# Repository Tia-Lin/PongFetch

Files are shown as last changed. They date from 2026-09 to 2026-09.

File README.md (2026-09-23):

# PongFetch · rev 3.0

**Pick.Play.** A 3D-printable table-tennis ball picker with a removable PVC handle.

Press the frame over 40 mm balls. Three flexible fins let the balls pass into a mesh net; eight folding latches secure the net. A six-finger collet and screw cap hold the handle without glue, so it can be reused.

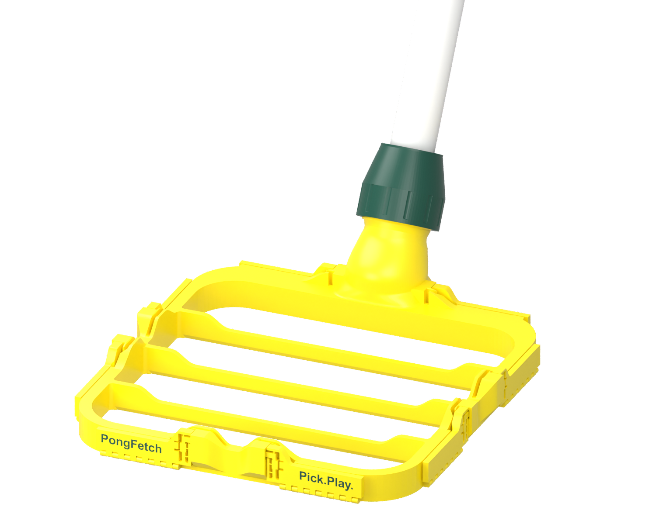
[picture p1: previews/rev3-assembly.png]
PongFetch assembled


**[Download rev 3.0](https://github.com/Tia-Lin/PongFetch/releases/tag/v3.0)** · [Printing](prints/PRINTING.md) · [Assembly](docs/ASSEMBLY.md) · [Accessories](Accessories/README.md) · [License](LICENSE.md)

## Make one

Print one frame, one collet and one cap. Add a fine mesh net and a PVC pipe matching the design's **21.34 mm outside diameter**. Measure the actual pipe before printing; the size printed on plumbing pipe is not its outside diameter. Net pins are 2.8 mm in diameter, so check that your mesh can pass over them.

| File | Use |
| --- | --- |
| [Frame 3MF](prints/PongFetch_Rev3_Frame.3mf) | Frame, eight folding latches, flush two-colour lettering and local bridge modifiers |
| [Handle parts 3MF](prints/PongFetch_Rev3_Handle_Parts.3mf) | One collet and one cap, in their saved print orientations |
| [Frame STL](SmallPicker.stl) | Single-colour frame; no visible flush lettering |
| [Collet STL](Collet.stl) · [Cap STL](ColletCap.stl) | Single-part meshes for your own slicer setup |

The release includes individual print files, an editable-design ZIP, a complete **Maker Bundle**, and SHA-256 checksums. GitHub's automatic source archive contains the repository; the Maker Bundle is the curated printing download.

The validated mechanical parts were printed in PETG. Review the saved **4 walls and 0.20 mm layers / first layer**. **Select your actual printer, plate and loaded materials, then re-slice both 3MF projects.** The files save different machine profiles; they are not ready-to-send G-code. See [the exact saved settings](prints/PRINTING.md).

After cooling, release the three thin first-layer ties at each latch. Place the net between the flap and frame, engage the pins through the mesh, and keep the net clear of the release spring. Seat the collet's locating skirt and hand-tighten the cap. No glue is needed.

## Accessories

Two optional attachments for the free end of the same PVC handle are now included in the Maker Bundle and in the separate [Accessories download](https://github.com/Tia-Lin/PongFetch/releases/download/v3.0/PongFetch_Accessories.zip).

| Accessory | Print project | Details |
| --- | --- | --- |
| Decorative end cap | [Two-colour end cap](Accessories/EndCap/PongFetch_EndCap_Logo_X2D_PETG_Basic.3mf) | User-selected ID 21.44 mm, OD 23.84 mm, 1.20 mm wall; flush paddle-and-ball logo |
| Removable hanger (D) | [Hanger and compression nut](Accessories/Hanger/PongFetch_Hanger_X2D_PETG_Basic.3mf) | Two printed parts; clamps to the pipe without glue or drilling |

Both accessory projects save X2D / 0.4 mm / PETG Basic / textured PEI / 0.20 mm layers / 4 walls, with supports disabled. Re-slice for the actual printer and loaded materials. The user has approved the end-cap fit and reported the hanger works well; long-term load capacity is not rated. See [Accessories](Accessories/README.md) for assembly and validation scope.

The 2026-09-22 accessory supplement leaves the core rev 3.0 geometry and published core print files unchanged. The `v3.0` tag still identifies the original core release; updated download bundles record their source commit in `PACKAGE_INFO.json`.

## What is validated?

The current frame, skirted collet and cap have been physically printed and reported stable and usable by the designer. Rev 3.0 adds four flush labels: `PongFetch`, `Pick.Play.`, `open source`, and `rev 3.0`. Their orientation is defined for the **closed, assembled flaps**.

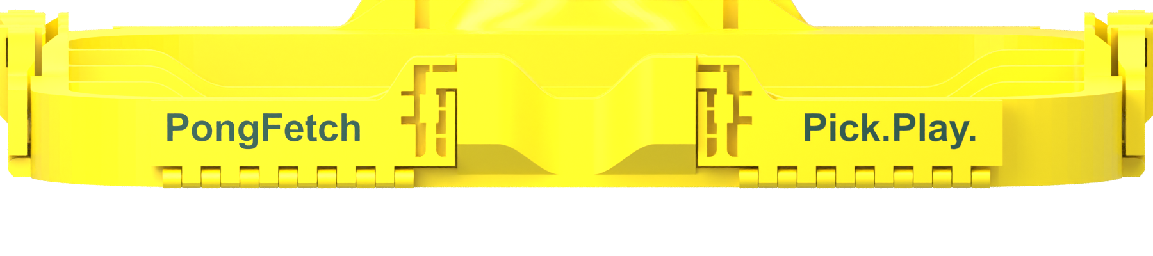
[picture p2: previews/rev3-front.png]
Front labels

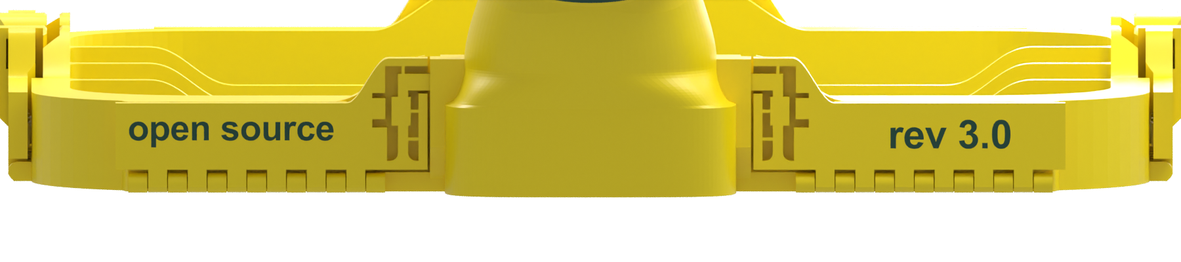
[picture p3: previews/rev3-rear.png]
Rear labels


The 0.60 mm text inlay and material partition were checked digitally. The coloured finish and long-term durability have not been established by those checks. This publication preserves the current CAD, STL and 3MF files; it adds no untested mechanical revisions. See [validation scope](docs/VALIDATION.md).

## Edit the design

Install [OpenSCAD](https://openscad.org/) and [BOSL2](https://github.com/BelfrySCAD/BOSL2) separately. Put BOSL2 in OpenSCAD's library search path. Open `SmallPicker.scad` with the other three SCAD files beside it.

| Source | Contents |
| --- | --- |
| `SmallPicker.scad` | Frame, flat-bottom fins, latch placement and part selection |
| `SideLatch.scad` | Side-release latches, net pins and first-layer ties |
| `ColletSocket.scad` | Socket, locating-skirt collet and screw cap |
| `Branding.scad` | Text, assembled orientation and inlay depth |

Choose `part` in the Customizer: `frame`, `cap`, `collet`, `assembly`, or `exploded`. For two colours, export `frame_base` and `frame_text`, then import them **as parts of one object at their shared coordinates**, without separately centering them. `Arial:style=Bold` is used for the text; use a licensed local font or change `brand_font` and recheck text fit. No font or BOSL2 files are bundled.

With Python 3 and OpenSCAD on your PATH:

```sh
python3 scripts/export_parts.py --parts cap collet
python3 scripts/verify_release.py
```

Omit `--parts` to also export the frame; that can take several minutes. Use `--openscad /path/to/openscad` if needed. The existing export baseline used OpenSCAD 2021.01; the exact installed BOSL2 revision was not recorded, so recheck exports after changing dependencies.

## Repository and contributions

This repository contains the product design, print files, documentation and compact verification reports. The product website is maintained separately; its application code is no longer part of this repository. Design downloads and releases remain available here. Slicer logs and old prototypes are excluded from the published tree.

For a bug report or improvement, [open an issue](https://github.com/Tia-Lin/PongFetch/issues) with the revision, printer, nozzle, material, layer height, wall count and a photo. For a design change, include editable source and describe what you tested. Keep print orientation, support-free printing and net routing in mind.

## License

The original design materials are **CC BY-NC-SA 4.0**: noncommercial copying, printing and adaptation are permitted under the license; shared work must retain attribution, identify changes and comply with ShareAlike. Commercial use requires separate permission where licensed rights are involved. Sharing editable source with a remix is encouraged, not an extra license requirement.

Read [LICENSE.md](LICENSE.md) for scope and attribution, the unmodified [official legal text](CC-BY-NC-SA-4.0.txt), and [third-party notices](THIRD_PARTY_NOTICES.md). Website application code and Python utilities remain outside the design-license grant.

Because commercial reuse is restricted, this is a **source-available design for noncommercial use**, not an OSI open-source project. The historical `open source` label on the model does not change the license.

## 中文快速说明

本套件为 rev 3.0：框身（含八只翻片）、压紧夹头、锁紧螺帽各一件。另需网袋和外径约 21.34 mm 的 PVC 管；先量实际管径。优先下载 Release 的 Maker Bundle，双色文字使用框身 3MF，单色 STL 不显示齐平嵌字。

保留已经验证的机械结构及最新打印项目。打开 3MF 后选择自己的打印机、材料和打印板并重新切片；两张打印盘保存的机器配置不同。释放每只翻片的三条首层细筋，再装网、安装可拆把手。详见[打印说明](prints/PRINTING.md)和[装配说明](docs/ASSEMBLY.md)。

可选 [Accessories 配件](Accessories/README.md) 已并入完整下载包：最终双色装饰帽，以及可拆卸 D 挂钩和旋紧环。已有主体可以单独下载 Accessories 包。

采用 **CC BY-NC-SA 4.0（署名—非商业性使用—相同方式共享）**，具体范围以 LICENSE.md 及官方许可原文为准。

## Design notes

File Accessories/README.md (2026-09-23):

# Accessories

Optional accessories for the **free end** of the PongFetch PVC handle. Choose the decorative cap or the removable hanger; both target a pipe with **21.34 mm actual outside diameter**.

| Accessory | Ready-to-slice project | Assembly and source |
| --- | --- | --- |
| End cap with flush paddle-and-ball logo | [End cap 3MF](EndCap/PongFetch_EndCap_Logo_X2D_PETG_Basic.3mf) | [EndCap](EndCap/README.md) |
| D removable hanger and compression nut | [Hanger 3MF](Hanger/PongFetch_Hanger_X2D_PETG_Basic.3mf) | [Hanger](Hanger/README.md) |

The end cap uses the user-selected **ID 21.44 mm / OD 23.84 mm / 1.20 mm wall** fit. It is decorative and is not a hanging attachment. The hanger clamps onto the tube without glue or drilling and releases by loosening its nut. The user has reported successful use of both designs; the hanger is not load-rated.

Both projects save **X2D, 0.4 mm nozzle, textured PEI, PETG Basic, 0.20 mm layers and four requested walls, supports disabled**. Open them in Bambu Studio, select the actual printer and spools, then re-slice. They contain no machine-ready G-code. The end cap is a single object with two colour parts; the hanger project contains its two separate printable pieces.

STLs, editable OpenSCAD source and compact verification records are included in each folder. EndCap source is standalone; Hanger source requires separately installed BOSL2. Trial directories and older fit variants have been removed from the active release.

Download the standalone **PongFetch_Accessories.zip** or the complete **PongFetch_Rev3_Maker_Bundle.zip** from the [rev 3.0 release](https://github.com/Tia-Lin/PongFetch/releases/tag/v3.0). The original core tag is unchanged; refreshed bundles identify their source commit in `PACKAGE_INFO.json`.

## 中文

Accessories 包含最终双色装饰帽，以及可拆 D 挂钩和旋紧环。两者用于 PVC 管的另一端，按需要二选一。帽子采用已试好的最紧尺寸，挂钩保留已验证结构；主体 rev 3.0 不变。

原型目录已清理。可以单独下载配件包，也可以下载已经包含配件的 Maker Bundle。打开 3MF 后按实际打印机和 PETG 料卷重新切片。装饰帽不能用于悬挂，挂钩安装方法见其说明。

Original design: PongFetch / Tia-Lin, **CC BY-NC-SA 4.0**. See [license scope](../LICENSE.md), [official legal text](../CC-BY-NC-SA-4.0.txt) and [third-party notices](../THIRD_PARTY_NOTICES.md).

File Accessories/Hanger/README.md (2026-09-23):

# PongFetch D — removable hanging eye

The user reports that D works very well. Its geometry and native printing project are unchanged. Older loose A end caps have been retired; the user-selected [final decorative cap](../EndCap/README.md) now includes the flush paddle-and-ball logo. Historical files remain available in Git history.

## D — removable hanging eye with integral clamp

Two parts: `Hanger_body.stl` integrates the eye, male thread and six flexible fingers; `Hanger_nut.stl` provides the female thread and compression cone. The render uses two colours to identify the parts; the supplied D project prints both in one colour.

| Feature | Dimension |
|---|---:|
| Unclamped bore | 21.74 mm (0.40 mm diametral clearance) |
| Straight finger wall / slots | 1.73 / 1.20 mm |
| Rounded slot-root relief | Ø2.40 mm |
| Compression cone | 15° to the axis |
| Male thread major diameter / pitch | 30.0 / 3.0 mm |
| Thread depth / diametral clearance | 1.0 / 0.60 mm |
| Body maximum diameter / height | 35.40 / 67.20 mm |
| Nut maximum diameter / height | 35.00 / 30.80 mm |
| Eye plate thickness / outer width | 6.40 / 34.00 mm |
| Eye aperture maximum width | 18.00 mm, pointed roof |
| Projection above nominal seated pipe end | About 39.5 mm |

The ring advances toward the eye when tightened. Its cone presses the fingers inward against the pipe. Loads pass from the hanging eye through the broad shoulder and integral body to friction at the pipe. Rounded slot roots and a gradual transition into the threaded section reduce abrupt section changes. The eye has a pointed, 45° roof to avoid a broad horizontal bridge. The pipe socket also has a 45° internal roof rather than a flat bridging ceiling.

The widened finger tips are about Ø27.99 mm and can pass through the female thread's nominal Ø28.60 mm minimum opening. This clearance was checked explicitly. The thread entry stays clear throughout the designed stroke.

`travel=0` in the source is an assembly reference position, **not the start of thread engagement**. From that position, cone contact begins at roughly 0.67 mm advance, and matching shoulder cones meet at approximately 2.0 mm. That leaves nominal room to take up the 0.20 mm radial pipe clearance and apply some preload. Actual force depends on the printed fingers and pipe. The shoulder is a travel stop, **not a torque limiter**; stop tightening once the pipe is held firmly, even if the shoulder has not seated.

### Assembly and trial

1. Slide the nut onto the free pipe end, with its large threaded opening toward that end.
2. Slip the body onto the pipe until seated against the internal roof.
3. Bring the nut up to the male thread, engage gently and hand-tighten toward the eye. Check that the body cannot readily rotate or pull off. Do not use pliers to force the shoulder closed.
4. To remove, loosen the nut until the fingers relax, then lift off the body.

First check thread engagement without the pipe, then check fit on the actual pipe. Mark the pipe at the body edge and test the empty picker close to a padded surface. Recheck for slip, rotation or cracks after repeated removal and a 24-hour hanging trial with the intended storage load. Do not treat this accessory as load-rated: PETG creep, layer adhesion and friction have not been physically measured. If the shoulder closes while the pipe still slips, revise the fit rather than applying more torque.

### Printing D

Use `PongFetch_Hanger_X2D_PETG_Basic.3mf`, or import the two STLs in their supplied orientations. Body: six finger tips on the bed, eye upright. Nut: smaller end down. The project adds a **2 mm external brim only to the body**, with 0.15 mm separation, to help its six separate starting feet; this is slicer-generated, not permanent breakaway ears in the CAD.

The D project uses X2D, 0.4 mm nozzle, textured PEI, Bambu PETG Basic, **0.20 mm first layer and subsequent layers, 4 walls, 20% gyroid, support disabled**. The D two-part slice estimates **1 h 45 min and 23.30 g**, including the saved brim/toolpath settings.

The upright body orientation prioritizes printable threads and fingers. It leaves layer interfaces across the hanging load direction; the wide eye and shoulder help distribute load, but do not eliminate that weakness. Do not assume slicing success proves long-term strength.

## Verification and source

`source/Hanger.scad` requires separately installed BOSL2 (BSD-2-Clause). Select `part="body"` or `"nut"` for print exports, or `"assembly"`, `"exploded"`, `"section"` for inspection. The actual STL meshes, thread-clearance scan, native slicing settings and layer toolpaths are documented in `verification/`. The user has reported successful use; this is not a quantified long-term load test.

Original design: PongFetch / Tia-Lin, **CC BY-NC-SA 4.0**. Official legal text is included at [../../CC-BY-NC-SA-4.0.txt](../../CC-BY-NC-SA-4.0.txt). BOSL2 and Bambu Studio/profile content retain their own terms. The tested rev3.0 picker is unchanged.

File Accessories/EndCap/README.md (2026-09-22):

# PongFetch — final decorative handle-end cap

The user selected the tightest equal-wall A3 sample on **2026-09-22**: cylindrical **ID 21.44 mm, OD 23.84 mm, wall 1.20 mm**. This final version preserves that fit and restores the flush two-colour paddle-and-ball logo. Earlier trial variants are retired from the active delivery; their history remains in Git. The D hanger is unchanged.

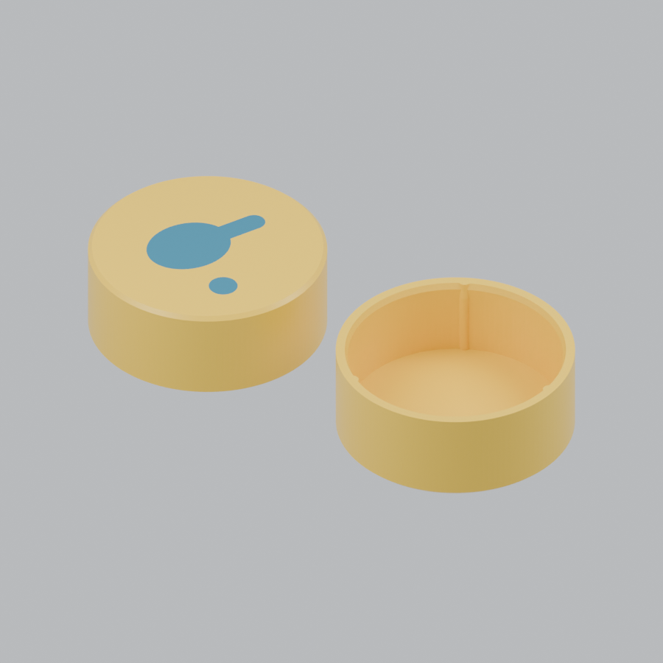
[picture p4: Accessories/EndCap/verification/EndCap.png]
Final cap, logo face and interior


## Dimensions and logo

| Feature | Selected value |
|---|---:|
| Target actual PVC OD | 21.34 mm |
| Cylindrical bore / outside diameter | 21.44 / 23.84 mm |
| Straight wall / closed face | 1.20 / 1.20 mm |
| Overall height / insertion depth | 9.20 / 8.00 mm |
| Three rounded rib contact diameter | 20.94 mm |
| Flush logo depth | 0.40 mm |

The assembled cap extends about 1.2 mm beyond the seated pipe end. The logo is on the outside closed face and adds no height. It occupies the first two 0.20 mm print layers, with 0.80 mm of body material behind it. Use two colours of PETG; the saved example is yellow with a dark-blue mark. The logo is co-printed, not a separate press-fit insert.

## Print

Open **`PongFetch_EndCap_Logo_X2D_PETG_Basic.3mf`**. It contains one assembled object with two correctly aligned parts: cap body and logo. Assign the actual PETG spools/nozzle mapping and re-slice. Print with the logo face on the bed and opening upward.

Saved settings: X2D, 0.4 mm nozzle, textured PEI, Bambu PETG Basic, 0.20 mm first and subsequent layers, four requested walls, 20% gyroid, no supports or brim. Thin sections contain only the wall lines that fit. The delivered project contains no G-code. The saved slice estimates **1.64 g and 18 minutes**; actual start-up, purge and material use can differ.

- `EndCap_body.stl` + `EndCap_logo.stl`: alternate multipart import; import together as parts of **one object**, preserve shared coordinates and assign colours. The logo mesh intentionally contains two pieces, paddle and ball.
- `EndCap_plain.stl`: complete single-colour fallback without a visible logo; byte-identical to the user-selected equal-wall A3 ID21.44 sample.
- `source/EndCap.scad`: standalone editable OpenSCAD source. Default `part="assembly"` previews both colours; export `body` and `inlay` for the logo version, or `cap` for the plain version. The final fit is the default; there is no trial-grade selector.

The user has approved the plain cap's fit. The logo version has been checked digitally for alignment, closed geometry, the same complete envelope and native support-free slicing; it has not yet been physically printed. This is a decorative cap, not a hanging attachment. Use the D hanger for suspension.

## 中文

最终采用你选中的最紧版本：ID 21.44 mm、OD 23.84 mm、壁厚 1.20 mm。内壁、凸筋和安装尺寸保持原样，补回齐平的双色的球拍＋乒乓球 Logo，不增加高度。

请使用双色 3MF，确认实际 PETG 颜色和喷嘴/料卷映射后重新切片。Logo 面贴床、开口向上。两个 STL 若手动导入，需要作为同一个对象的两个部件导入，不能分别居中或单独打印 Logo。单色备用 STL 与已通过试用的样品完全相同。

## License

Original design: PongFetch / Tia-Lin, **CC BY-NC-SA 4.0**. Official legal text is included in the download bundle and repository root. Bambu Studio/profile content retains its own terms. Geometry and slice checks are recorded in `verification/`.

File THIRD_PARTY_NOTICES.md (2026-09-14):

# Third-party components

The original PongFetch design is covered by LICENSE.md. Third-party components retain their own licenses and are not relicensed by PongFetch.

- **BOSL2** — https://github.com/BelfrySCAD/BOSL2 — BSD-2-Clause. Required by the SCAD design; install separately. Keep its copyright and license notices when redistributing the library. The library is not included in the design-source ZIP.
- **OpenSCAD** — https://openscad.org — design tool, installed separately; not included in the download.
- **Arial Bold** — used by `Branding.scad`. Install a properly licensed local font or change `brand_font` to a font available to you. Font files are not included. Recheck geometry and text fit after changing the font.
- **Bambu Studio profiles** — the 3MF projects retain saved machine and material settings. The PongFetch design license applies to original PongFetch design content, not third-party software, profile content or trademarks.

Official CC legal text is included unmodified in CC-BY-NC-SA-4.0.txt. The license name and text are provided by Creative Commons; this is not an endorsement by Creative Commons.

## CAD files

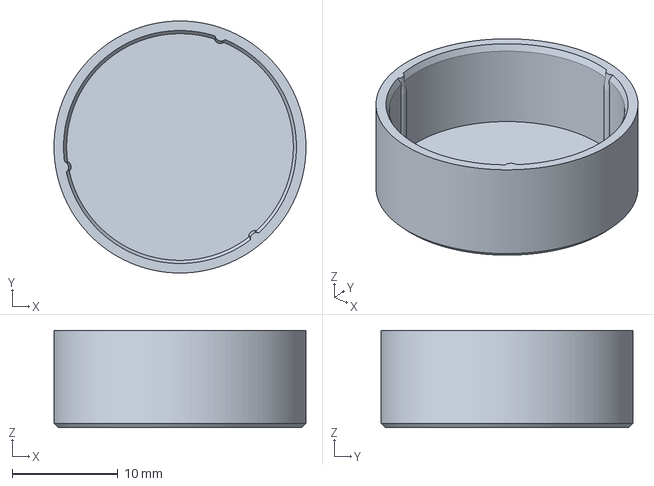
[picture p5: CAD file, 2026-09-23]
Accessories/EndCap/PongFetch_EndCap_Logo_X2D_PETG_Basic.3mf
23.8 x 23.8 x 9.20 mm

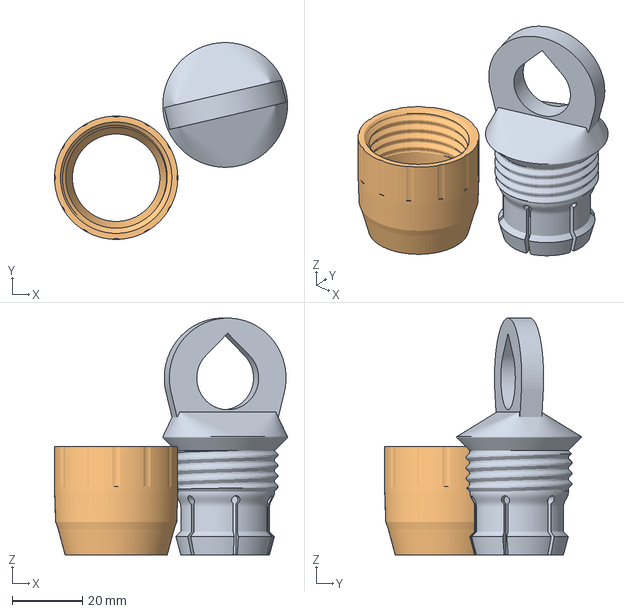
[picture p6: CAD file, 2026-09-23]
Accessories/Hanger/PongFetch_Hanger_X2D_PETG_Basic.3mf
66.1 x 55.8 x 67.2 mm
D_body_1
D_nut_1

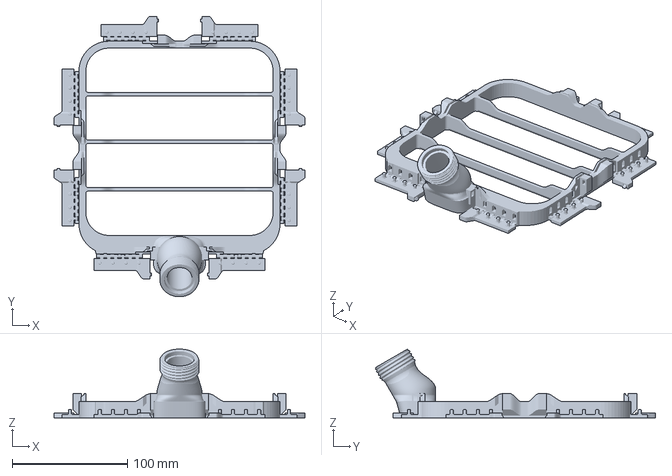
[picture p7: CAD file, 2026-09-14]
prints/PongFetch_Rev3_Frame.3mf
217.4 x 242.9 x 59.6 mm

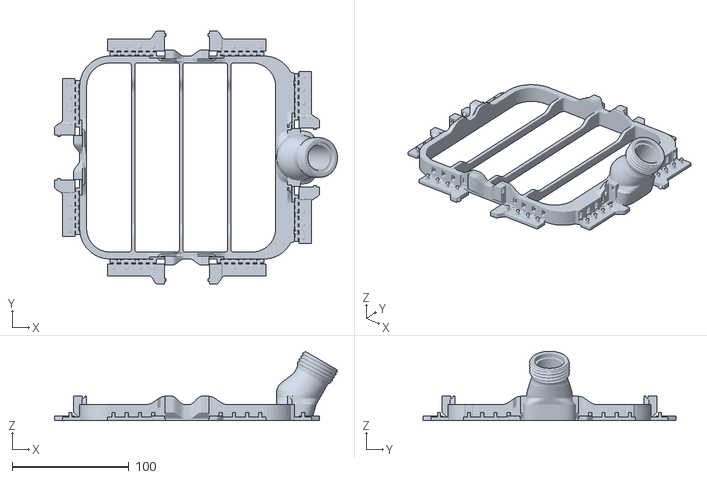
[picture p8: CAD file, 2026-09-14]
SmallPicker.stl
242.9 x 217.4 x 59.6

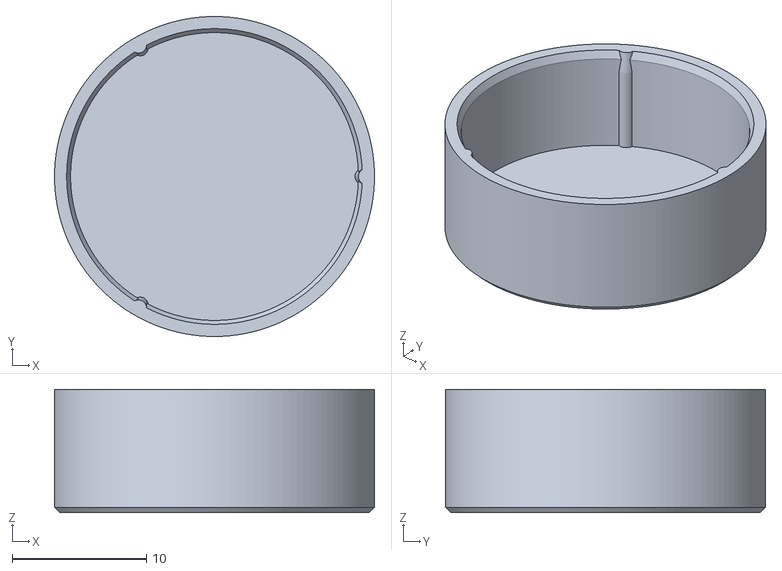
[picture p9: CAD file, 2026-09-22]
Accessories/EndCap/EndCap_body.stl
23.8 x 23.8 x 9.20

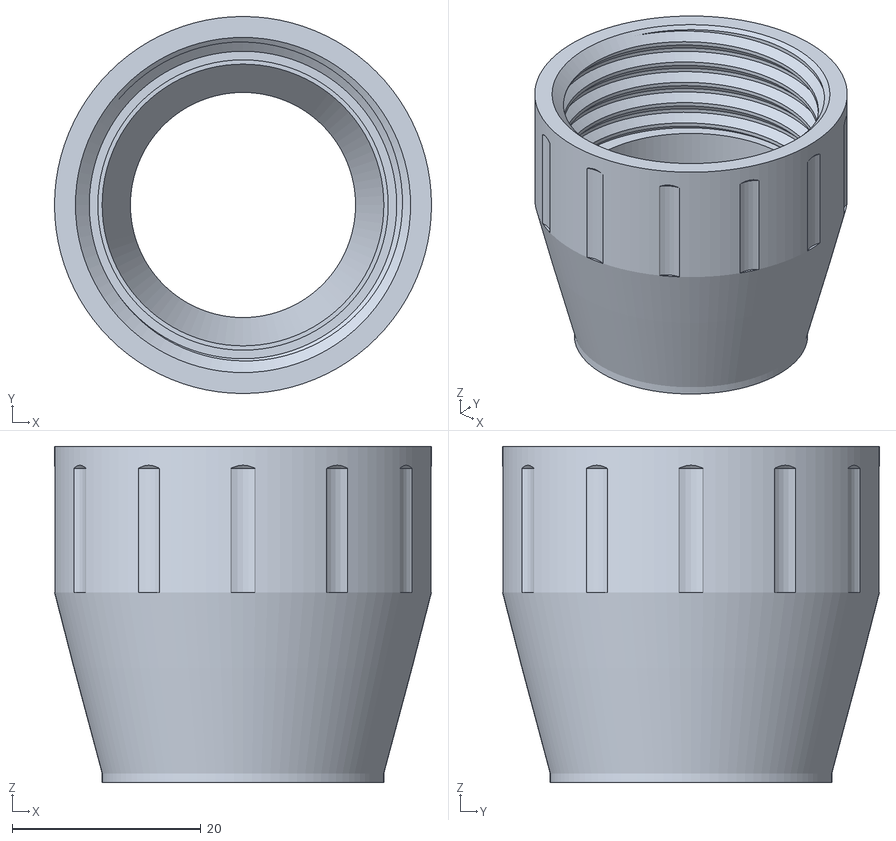
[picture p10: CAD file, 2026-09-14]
ColletCap.stl
40.0 x 40.0 x 35.7

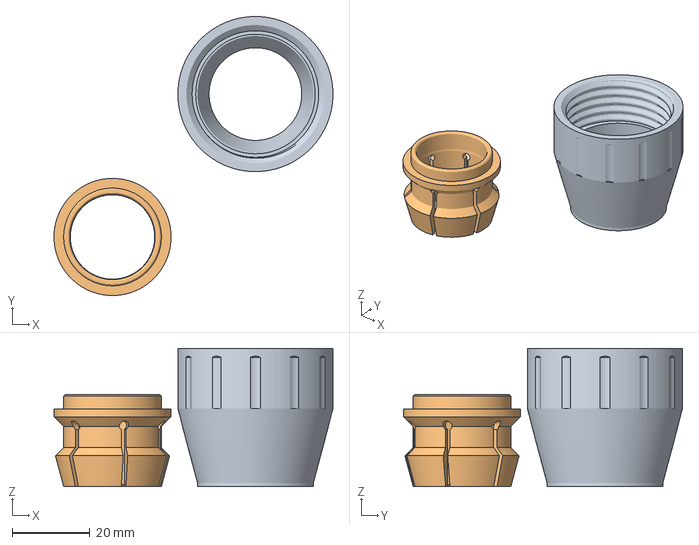
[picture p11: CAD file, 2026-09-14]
prints/PongFetch_Rev3_Handle_Parts.3mf
71.9 x 71.9 x 35.7 mm
ColletCap_1
Collet_1

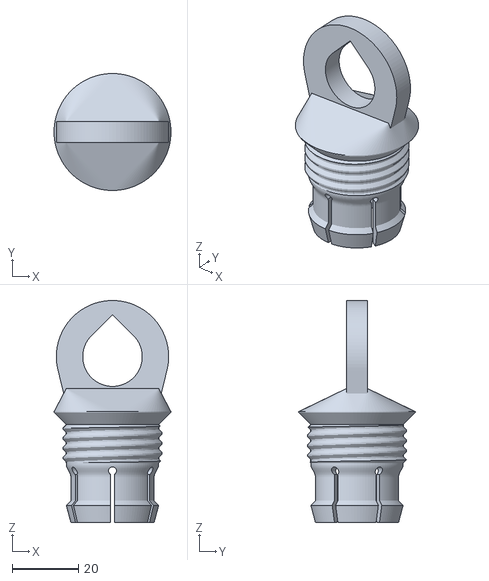
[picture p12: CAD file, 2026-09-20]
Accessories/Hanger/Hanger_body.stl
35.4 x 35.4 x 67.2

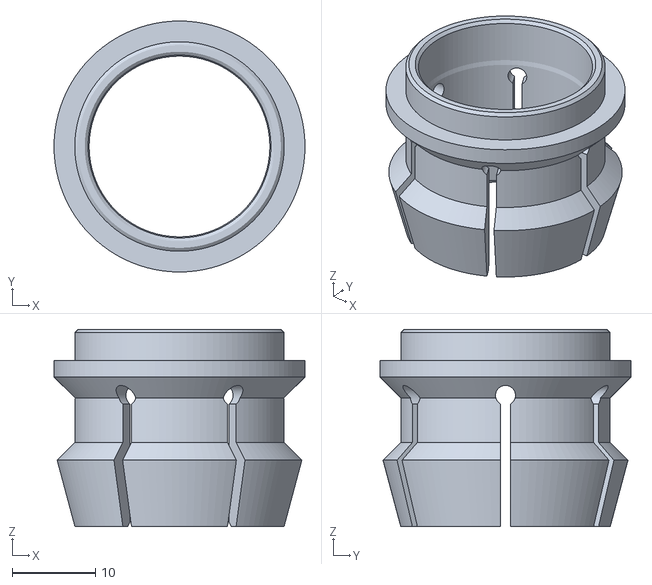
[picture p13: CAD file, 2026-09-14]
Collet.stl
30.2 x 30.2 x 23.8

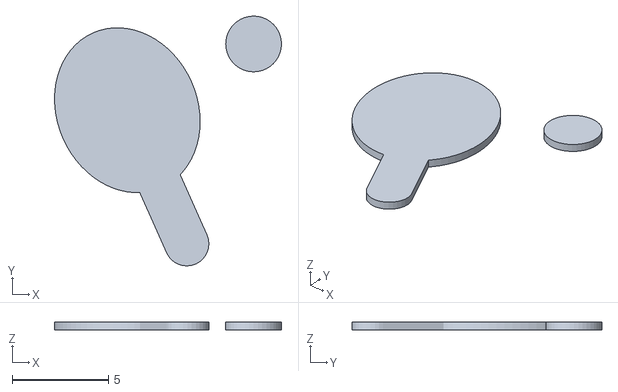
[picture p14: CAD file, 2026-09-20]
Accessories/EndCap/EndCap_logo.stl
11.8 x 13.0 x 0.4

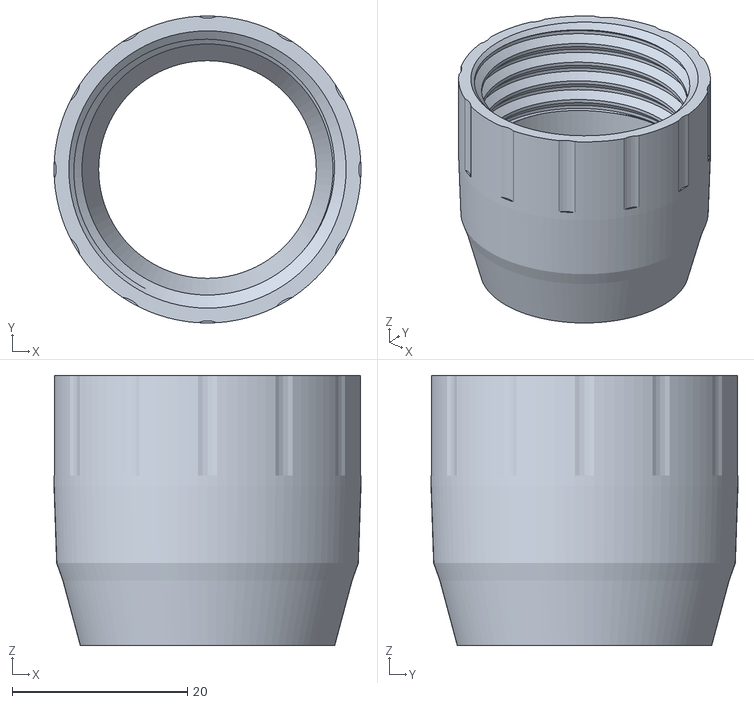
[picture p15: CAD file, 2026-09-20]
Accessories/Hanger/Hanger_nut.stl
35.0 x 35.0 x 30.8

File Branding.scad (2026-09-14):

// Rev 3.0: flush, three-layer inlays on the outward face of four closed flaps.
// Text is specified in the CLOSED pose; mirrored stations compensate glyph handedness.
use <SideLatch.scad>
brand_depth=0.60;
brand_font="Arial:style=Bold";
brand_labels=["PongFetch","Pick.Play.","open source","rev 3.0"];
brand_stations=[4,5,6,7];
module brand_local_text(label, mirrored=false) {
    translate([-4,-3.6+brand_depth,9.1]) rotate([90,0,0])
        scale([mirrored ? -1 : 1,1,1]) linear_extrude(brand_depth)
            text(label,size=label=="open source" ? 4.0 : 4.5,font=brand_font,halign="center",valign="center",spacing=1,$fn=32);
}
module brand_local_print(k) {
    sl_closed_to_print() brand_local_text(brand_labels[k],k==1 || k==3);
}

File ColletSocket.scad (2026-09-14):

// PETG prototype: reusable PVC collet and screw cap.
// Lengths are millimetres. All local geometry uses the socket axis as +Z.
include <BOSL2/std.scad>
include <BOSL2/threading.scad>

// Measure your actual pipe before printing the complete picker.
pipe_od = 21.34;
socket_bore_d = 21.75;
collet_bore_clearance = 0.40;  // DIAMETRAL, independent of thread clearance
thread_diametral_clearance = 0.60;
cone_radial_clearance = 0.20;

socket_angle = 30;
socket_length = 50.3;         // 5 mm shorter than the physically tested collet revision
socket_bottom = 6.25;
socket_lower_d = 30;
thread_major_d = 34;
thread_pitch = 3;
thread_depth = 1.0;
thread_angle = 90;           // 45-degree flanks for axial printing
thread_root_d = thread_major_d - 2*thread_depth;
thread_band_length = 12.5;
socket_pilot_d = 25.70;      // retain this pocket so the previous pilot collet still fits
socket_pilot_depth = 4.2;

// Restore the pilot and preserve the flat flange seat at local Z4.
collet_seat_z = 4.0;
collet_pilot_d = 25.20;
collet_pilot_trim = 0.25;
collet_bottom_chamfer = 0.4;
collet_collar_bore_d = 22.0;
collet_collar_relief_z = 6.0;
collet_flange_d = 30.20;
collet_flange_h = 2.0;
collet_finger_d = 25.20;
// Printed tips-down: expand into the full-thickness flange at 45 degrees.
collet_flange_ramp_h = (collet_flange_d-collet_finger_d)/2;
collet_height = 24.0;        // upper local Z; tips-down printed height is 24 - 0.25 = 23.75
collet_slot_count = 6;
collet_slot_width = 1.2;
collet_slot_root_z = 8.2;
collet_slot_root_d = 2.4;
cone_half_angle = 15;
cone_length = 8;

cap_outer_d = 40;
cap_grip_depth = 0.35;       // shallow grooves preserve the hoop wall
cap_cone_wall = 3.0;         // radial wall following the upper internal taper
cap_start_above_thread_base = 1.0;
cap_max_travel = 3.2;        // geometric stop, NOT a torque limiter
cap_lip_h = 1.0;
cap_chamber_d = 30.8;        // clears flange; forms stop against socket rim

cs_eps = 0.02;
cs_fn = 96;
cone_start_z = collet_height-cone_length;
cone_bottom_d = collet_finger_d + 2*cone_length*tan(cone_half_angle);
cone_ramp_h = (cone_bottom_d-collet_finger_d)/2;
collet_assembly_z = socket_length-collet_seat_z;
cap_bottom_z = socket_length-thread_band_length+cap_start_above_thread_base;
cap_thread_top_z = socket_length+cap_max_travel;
cap_cone_start_z = collet_assembly_z+cone_start_z;
cap_cone_end_z = collet_assembly_z+collet_height+cap_max_travel;
cap_top_z = cap_cone_end_z+cap_lip_h;
cap_height = cap_top_z-cap_bottom_z;
cap_top_bore_d = collet_finger_d + 2*cone_radial_clearance
    -2*cap_max_travel*tan(cone_half_angle);
cap_taper_start_z = cap_thread_top_z+0.8;
cap_cone_outer_bottom_d = cone_bottom_d+2*cone_radial_clearance+2*cap_cone_wall;
cap_outer_top_d = cap_top_bore_d+2*cap_cone_wall;

// Male and female use the same reference length and axial origin.
// BOSL2 shifts the internal symmetric profile by half a pitch; the internal
// mask is rotated 180 degrees to align its cavity with the external ridge.
thread_reference_z = socket_length-25;
thread_reference_h = 32;

assert(collet_finger_d > pipe_od+collet_bore_clearance+2.5);
assert(collet_flange_d < thread_root_d+thread_diametral_clearance);
assert(cap_chamber_d > collet_flange_d+0.3);
assert(cap_chamber_d < thread_root_d);
assert(cap_top_bore_d > pipe_od+0.8);
assert((thread_root_d-socket_pilot_d)/2 > 2.5);
assert(collet_collar_bore_d >= pipe_od+collet_bore_clearance);
assert(collet_collar_relief_z+0.6 < collet_slot_root_z-collet_slot_root_d/2);
assert(collet_pilot_trim+collet_bottom_chamfer < collet_seat_z);
assert(collet_pilot_d < socket_pilot_d);
assert(collet_seat_z-collet_pilot_trim < socket_pilot_depth);
assert(collet_seat_z+collet_flange_h+collet_flange_ramp_h < cone_start_z-cone_ramp_h);
assert(cap_taper_start_z < cap_cone_start_z);
assert(cap_outer_d > cap_cone_outer_bottom_d);
assert((cap_outer_d-thread_major_d-thread_diametral_clearance)/2-cap_grip_depth > 2.2);
assert(socket_length-0.8-(cap_bottom_z+1.5) >= 3*thread_pitch);

module cs_axial_clip(z0,z1,diam=120) {
    translate([-diam/2,-diam/2,z0]) cube([diam,diam,z1-z0]);
}

module cs_thread(internal=false) {
    translate([0,0,thread_reference_z])
      rotate([0,0,internal ? 180 : 0])
        trapezoidal_threaded_rod(d=thread_major_d,
            l=thread_reference_h, pitch=thread_pitch,
            thread_depth=thread_depth, thread_angle=thread_angle,
            internal=internal, blunt_start=false, bevel=false,
            anchor=BOT, $slop=internal ? thread_diametral_clearance/4 : 0,
            $fn=cs_fn);
}

module socket_placement(frame_outer_x=184.2) {
    translate([frame_outer_x/2+13,0,34])
        rotate([0,socket_angle,0]) translate([0,0,-30]) children();
}

module socket_bore_local() {
    translate([0,0,socket_bottom])
        cylinder(d=socket_bore_d,h=socket_length+2,$fn=cs_fn);
    translate([0,0,socket_length-socket_pilot_depth])
        cylinder(d=socket_pilot_d,h=socket_pilot_depth+2,$fn=cs_fn);
    // Small pilot entrance chamfer. The flat annular seat remains intact.
    translate([0,0,socket_length-0.4])
        cylinder(d1=socket_pilot_d,d2=socket_pilot_d+0.8,
            h=0.4+cs_eps,$fn=cs_fn);
}

module socket_shell_local() {
    difference() {
        union() {
            cylinder(d=socket_lower_d,h=socket_length-thread_band_length-3,$fn=cs_fn);
            translate([0,0,socket_length-thread_band_length-3-cs_eps])
                cylinder(d1=socket_lower_d,d2=thread_root_d,h=3+2*cs_eps,$fn=cs_fn);
            translate([0,0,socket_length-thread_band_length-cs_eps])
                // Slight overlap avoids coincident root faces in binary STL.
                cylinder(d=thread_root_d+2*cs_eps,h=thread_band_length+cs_eps,$fn=cs_fn);
            intersection() {
                cs_thread();
                cs_axial_clip(socket_length-thread_band_length,socket_length-0.8);
                // Lead-in tapers to the root diameter at the upper end.
                union() {
                    cylinder(d=thread_major_d+2,h=socket_length-2,$fn=cs_fn);
                    translate([0,0,socket_length-2])
                        cylinder(d1=thread_major_d+2,d2=thread_root_d,h=1.2,$fn=cs_fn);
                }
            }
        }
        socket_bore_local();
    }
}
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

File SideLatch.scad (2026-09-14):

// Integrated side latch, derived from R7; compact housing and 0.95 mm engagement.
// Local +X points toward the middle of the frame edge; +Y points toward balls.
// Closed axes: X along frame; +Y toward balls; +Z up. Flat printing is the R4 pose.
include <BOSL2/std.scad>
include <BOSL2/hinges.scad>

$fn=64;
eps=0.02;
axis=[0,-2.1,1.5];
panel_right=26.6;
panel_top=21.0;
latch_engagement=0.95; // Midpoint between the earlier 0.8 mm and R9 1.1 mm.
latch_nose_x=27.0+latch_engagement;
roof_bottom=3.0; // Print Z; 0.6 mm above the 2.4 mm-thick thumb/head.
roof_top=4.2;
net_pin_x=[-17,-17/3,17/3,17];
net_lane_front=2.4;
net_lane_back=4.4;
frame_top=14;
lane_floor_front=12.6; // R6 depth 16.8 -> 8.4 mm from Z21.
lane_floor_back=12.0; // R6 depth 18 -> 9 mm from Z21.
function sl_smooth01(t)=t*t*(3-2*t);
function sl_blend_top(x0,x1)=
    [for(i=[32:-1:0]) [x0+(x1-x0)*i/32,
        frame_top+(panel_top-frame_top)*sl_smooth01(i/32)]];

module sl_original_hinge(inner) {
    knuckle_hinge(length=40,segs=13,offset=2.1,inner=inner,
        clearance=-1.5,knuckle_diam=3,arm_angle=45,gap=0.15,
        in_place=true,clip=1.5) children();
}
module sl_fixed_leaf() {
    cuboid([40,3,5],anchor=TOP+BACK,rounding=1,edges=[BOT+LEFT,BOT+RIGHT]);
}
module sl_moving_leaf() {
    cuboid([40,3,14],anchor=TOP+BACK,rounding=1,edges=[BOT+LEFT,BOT+RIGHT]);
}
module sl_original_pair() {
    translate([0,0,3]) xrot(90)
        sl_original_hinge(false) {
            position(BOT) sl_fixed_leaf();
            up(0.6) attach(BOT,TOP,inside=true) tag("")
                sl_original_hinge(true) position(BOT) sl_moving_leaf();
        }
}
module sl_closed_to_print() {
    multmatrix([[1,0,0,0],[0,0,-1,-0.6],[0,1,0,3.6],[0,0,0,1]]) children();
}
module sl_prism_x(x0,width,profile) {
    translate([x0,0,0])
        multmatrix([[0,0,1,0],[1,0,0,0],[0,1,0,0],[0,0,0,1]])
            linear_extrude(width) polygon(profile);
}
module sl_closed_box(x,y,z,dx,dy,dz) { translate([x,y,z]) cube([dx,dy,dz]); }
module sl_prism_y(y0,depth,profile) {
    translate([0,y0+depth,0]) rotate([90,0,0])
        linear_extrude(depth) polygon(profile);
}
module sl_top_envelope_closed(x0,x1) {
    sl_prism_y(-30,60,concat([[-40,-30],[40,-30],[40,panel_top]],
        sl_blend_top(x0,x1),[[-40,frame_top]]));
}
module sl_frame_height_blend() {
    // Add supported material above the existing frame, then cut the net lane.
    // Tangent at both ends: no abrupt 7 mm step into the tall receiver.
    sl_prism_y(1.8,4.2,concat([[12,frame_top-eps],[27,frame_top-eps]],
        sl_blend_top(12,27)));
}

module sl_spring_bay_closed() {
    // Exterior recess: narrow around the stem and wide around the thumb/head.
    sl_closed_box(20.3,-3.7,5.0,4.9,3.2,5.2+eps);
    sl_closed_box(18.0,-3.7,10.2,7.2,3.2,5.4);
    sl_closed_box(20.0,-3.7,15.6,5.2,3.2,4.2);
    // Only the nose exit interrupts the right bridge-support rail.
    sl_closed_box(25.2-eps,-3.7,15.5,panel_right-25.2+2*eps,3.2,4.3);
}
module sl_rigid_body_untrimmed_print() {
    difference() {
        union() {
            sl_original_pair();
            translate([-22,-panel_top-0.6,0])
                cube([panel_right+22,panel_top-3.6,3]);
        }
        sl_closed_to_print() sl_spring_bay_closed();
    }
    // Side/top/root rails support a short bridge over the exterior spring bay.
    difference() {
        translate([16.5,-panel_top-0.6,3-eps])
            cube([panel_right-16.5,panel_top-3.6,roof_bottom-3+eps]);
        sl_closed_to_print() {
            sl_closed_box(20.3,-0.7,5.0,4.9,1.0,5.2+eps);
            sl_closed_box(18.0,-0.7,10.2,7.2,1.0,5.4);
            sl_closed_box(20.0,-0.7,15.6,5.2,1.0,4.2);
            sl_closed_box(25.2-eps,-0.7,15.5,panel_right-25.2+2*eps,1.0,4.3);
        }
    }
    // Unbroken net-contact skin. The seam and spring are on the hand side.
    translate([16.5,-panel_top-0.6,roof_bottom])
        cube([panel_right-16.5,panel_top-3.6,roof_top-roof_bottom]);
    // 45-degree blend from the old net plane to the raised skin.
    translate([0,-4.2,0]) rotate([90,0,0]) linear_extrude(panel_top-3.6)
        polygon([[15.3,3-eps],[16.5,3-eps],[16.5,roof_top]]);
    // Thumb over-travel stop, attached to the rigid wall, not to the spring.
    sl_closed_to_print() sl_closed_box(17.8,-3.6,11.5,2.25,2.8,3.3);
}
module sl_rigid_body_print() {
    intersection() {
        sl_rigid_body_untrimmed_print();
        // Trim the unused high left shoulder; preserve the upper-head bridge rail.
        sl_closed_to_print() sl_top_envelope_closed(14,20.5);
    }
}
module sl_latch_head_closed() {
    // The flat -Y face is the retaining face; only the incoming face is ramped.
    translate([0,0,16.0]) linear_extrude(2.6)
        polygon([[22.0,-3.6],[latch_nose_x,-3.6],[latch_nose_x,-3.1],
                 [latch_nose_x-1.4,-1.2],[22.0,-1.2]]);
}
module sl_spring_closed() {
    // Root overlap below Z5; X is the intended bending/withdrawal direction.
    sl_closed_box(22.0,-3.6,4.7,1.6,1.6,12.6);
    // Concave R1.2 root transitions in the intended bending plane.
    translate([0,-2.0,0]) rotate([90,0,0]) linear_extrude(1.6)
        polygon(concat([[20.8,4.7],[24.8,4.7]],
            [for(a=[270:-5:180]) [24.8+1.2*cos(a),6.2+1.2*sin(a)]],
            [for(a=[0:-5:-90]) [20.8+1.2*cos(a),6.2+1.2*sin(a)]]));
    // A 1.2 mm gap on its right gives access for a sideways finger push.
    sl_closed_box(21.0,-3.6,10.5,3.0,2.4,4.5);
    sl_latch_head_closed();
}
module sl_net_pin_closed(x) {
    translate([x,-0.62,7.2]) rotate([-90,0,0]) {
        cylinder(d=2.8,h=3.92,$fn=48);
        translate([0,0,3.92-eps]) cylinder(d1=2.8,d2=2.2,h=0.3+eps,$fn=48);
    }
    sl_closed_box(x-1.8,-0.62,5.4,3.6,0.37,3.6);
}
module sl_pin_pocket(x) {
    translate([x,4.1,0]) rotate([90,0,0]) linear_extrude(4.1+eps)
        polygon([[-1.9,5.3],[1.9,5.3],[1.9,10.1],[0,12],[-1.9,10.1]]);
}
module sl_net_lane_cut(end_x=33.52) {
    // A continuous, top-open passage behind the latch, open at both X ends.
    // Half the R6 depth; net rises from the pins into this shallow passage.
    sl_prism_x(23.5,end_x-23.5,[[net_lane_front,lane_floor_front],
        [net_lane_back,lane_floor_back],
        [net_lane_back,20.6],[net_lane_back+0.4,21.0],
        [net_lane_back+0.4,22.0],[net_lane_front-0.4,22.0],
        [net_lane_front-0.4,21.0],[net_lane_front,20.6]]);
}
module sl_guide_edge_reliefs(include_far=true) {
    // Widen the inlet in plan while its floor rises from Z10 to Z12.6.
    // The right pin pocket ends at X18.9; the lower frame stays connected.
    intersection() {
        translate([0,0,10]) linear_extrude(12)
            polygon([[20.5,1.8-eps],[23.5+eps,net_lane_back],
                     [23.5+eps,1.8-eps]]);
        sl_prism_y(-1,8,[[20.5,10],[23.52,12.61734],
            [23.52,22],[20.5,22]]);
    }
    // The entering mesh sees a ramp toward the wide lane, not a square ledge.
    translate([0,0,lane_floor_front]) linear_extrude(22-lane_floor_front)
        polygon([[23.5-eps,net_lane_front+eps],
                 [24.1,net_lane_front+eps],[23.5-eps,1.8]]);
    // Ease both lips at the open far end of the net passage.
    if(include_far) translate([0,0,lane_floor_back]) linear_extrude(22-lane_floor_back) {
        polygon([[33.1,net_lane_front+eps],[33.5+eps,net_lane_front+eps],
                 [33.5+eps,net_lane_front-0.4]]);
        polygon([[33.1,net_lane_back-eps],[33.5+eps,net_lane_back-eps],
                 [33.5+eps,net_lane_back+0.4]]);
    }
}
module sl_receiver_closed(handle=false) {
    difference() {
        intersection() {
          union() {
            // R5 retaining lip, insertion ramp clearance and 45-degree brace.
            sl_prism_x(27.0,6.5,[[0,0],[6,0],[6,21],[-5.2,21],[-5.2,7.2],[0,2.0]]);
            // Fixed overlap shields the moving-cover seam from the net side.
            // Its underside grows outward at 45 degrees from the frame.
            sl_prism_x(23.5,3.52,[[1.8,2.4],[6,2.4],[6,21],[1.2,21],[1.2,3.0]]);
          }
          sl_top_envelope_closed(12,27);
        }
        // Blind outer end: keep 1.2 mm of solid wall at X32.3..33.5.
        sl_closed_box(26.9,-3.95,14.6,5.4,3.25,4.7);
        sl_net_lane_cut(handle ? 28.6 : 33.52);
        sl_guide_edge_reliefs(!handle);
    }
}
module sl_rigid_additions_print() {
    sl_closed_to_print() {
        for(x=net_pin_x) sl_net_pin_closed(x);
    }
}
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

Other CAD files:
Accessories/EndCap/EndCap_plain.stl
SmallPicker.scad
Accessories/EndCap/source/EndCap.scad
Accessories/Hanger/source/Hanger.scad
accessories/end-cap-a3/source/EndCapA.scad
accessories/handle-tops-prototype-1/source/EndCapA.scad
accessories/handle-tops-prototype-1/source/HangerD.scad

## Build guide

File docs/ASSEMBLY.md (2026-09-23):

# Rev 3.0 assembly / 装配

1. Let the printed parts cool. Release the three first-layer ties at each of the eight latches. Check that every spring moves and returns freely. The inlaid lettering is permanent; do not peel it off.
2. Place the net between the flap and frame and pass the net pins through the mesh. Route the net along the channels between adjacent latches, leaving a little slack at the corners. Close each flap through approximately 90°. Keep the mesh away from the elastic release mechanism and check all eight latches are engaged.
3. Slide the cap and collet onto the PVC pipe. Insert the pipe into the socket, seat the collet's locating skirt, and place its flange flat against the socket rim. Hand-tighten the cap until the pipe no longer slips; confirm it can be loosened and removed again. No glue is required.
4. Try a few 40 mm balls on a flat floor. Press down to pass the balls through the fins into the net. Check net retention and handle grip. Tip the picker to let balls leave through the open end of the net.

The four labels are oriented for reading from outside the closed frame: front (away from the handle) `PongFetch` / `Pick.Play.`; rear (near the handle) `open source` / `rev 3.0`.

## 中文

1. 冷却后逐一抠断八只翻片各自的三条首层细筋，确认舌片自由回弹。嵌字是永久部分，不要剥除。
2. 网放在翻片与外框之间，用挂网销穿入网孔；沿相邻两扣之间的通道走网，角部留适当松量。翻片旋转约 90° 后锁住，网不能压在解锁弹片上。
3. 螺帽和夹头套上 PVC 管，再插入管座。定位裙进入座孔，法兰贴住端面，手拧螺帽并检查防滑和可拆性，不需要胶水。
4. 用少量球试捡，检查网与把手固定情况。倒球时从网袋开放端倒出。

## Optional handle-end accessories

Use either the [decorative end cap](../Accessories/EndCap/README.md) or the [removable hanger](../Accessories/Hanger/README.md) on the free end of the PVC tube. The decorative cap is not a suspension attachment. For hanging, slide the hanger nut onto the tube first, seat the hanger body, then hand-tighten the nut toward the eye.

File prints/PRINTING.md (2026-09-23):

# Rev 3.0 printing / 打印与清理

Use [the frame project](PongFetch_Rev3_Frame.3mf) and [the handle-parts project](PongFetch_Rev3_Handle_Parts.3mf). Both are editable, unsliced 3MF projects. Select your actual printer, plate, nozzle and material, then re-slice. Preserve the part orientations and the frame's eight local bridge modifiers.

## Saved settings in this release

These are the latest saved project settings, not a claim that both plates were printed on the same machine.

| Setting | Frame | Collet + cap |
| --- | --- | --- |
| Saved machine | Bambu Lab H2D, 0.4 mm nozzle | Bambu Lab X1 Carbon, 0.4 mm nozzle |
| Walls | 4 | 4 |
| Layer / first-layer height | 0.20 / 0.20 mm | 0.20 / 0.20 mm |
| Infill | 15%, grid | 15%, grid |
| Assigned material | Body: slot 4, PETG Basic, yellow; text: slot 2, PETG-CF, green | Slot 1, PETG Basic |
| Supports | Disabled | Disabled |

The frame also retains unused material slots 1, 3 and 5. These are not extra materials you must load. Map the body and text to your actual filaments; the saved PETG-CF text profile is not a requirement or a separately validated material pairing. The mechanical baseline used PETG. Changing material or machine profiles requires another slice review. Do not infer a profile from the preview colour.

## Frame

The frame and lettering are two normal parts of one object. Do not separate or independently reposition them. Text is flush with the print-bed face and 0.60 mm deep; at the saved layer height it occupies the first three layers. Use the 3MF for colour; the single-colour STL has the full solid envelope and no visible inlaid text.

The open frame footprint is approximately **242.9 × 217.4 mm**, before any purge tower or brim. Check the complete layout on your selected printer. The three fins have a 1.2 mm flat base at the bed. Inspect the first-layer preview, small springs and bridge directions before printing.

Let the plate cool. From the print-bed side, release the **three internal ties at each of the eight latches** individually. Each tie is 0.50 mm wide and 0.20 mm thick. Check that the spring moves freely and returns before closing the flap. There are no external adhesion ears to remove. Changing first-layer height can change how these ties slice.

## Collet and cap

Print one of each. Keep the collet **six fingers down, locating skirt up**. Its saved 3 mm outer brim and 0.15 mm brim gap are retained. Keep the cap in its saved orientation. Remove the collet brim carefully, then check the slots and mating surfaces before assembly.

## Validation

The mechanical baseline has physical print feedback. Earlier Rev 3.0 digital checks confirmed the colour partition, assembled text direction and text paths in a native Bambu Studio slice. The subsequently saved printer/material settings are preserved here; those earlier logs do not certify this exact profile combination. The release checks archive integrity, mesh topology and current settings, not a new physical print. See [validation details](../docs/VALIDATION.md).

## 中文要点

- 两张 3MF 都需要按自己的机器、喷嘴、打印板及实际装料重新切片。框身保存 H2D 配置，小件保存 X1 Carbon 配置；均为 4 圈墙、0.20 mm 层高及首层。
- 当前框身主体指定材料槽 4（黄色 PETG Basic），文字指定槽 2（绿色 PETG-CF）；其余槽位未参与打印。按实际材料映射，不必为了预览颜色购买对应材料。这个混合预设组合不等于已经完成实打验证。
- 保留八个桥接修改器、双色零件的相对位置和原有打印方向。检查首层及换色塔的位置。
- 冷却后逐一抠断八只翻片各自的上、中、下三条首层细筋，再检查回弹；齐平文字不能剥除。
- 夹头六瓣朝下、定位裙朝上，保留小件盘的夹头 brim。框身、夹头和帽的机械外形没有因本次发布改变。

## Accessories

The [Accessories folder](../Accessories/README.md) contains the end-cap and hanger print projects. Both save X2D, 0.4 mm, textured PEI, PETG Basic, 0.20 mm layers and four walls, support disabled. The end-cap logo is flush and bed-facing; the hanger body prints finger-tips-down with a 2 mm external brim. These are independent projects and do not change the core profiles above. Re-slice for your actual machine and materials.

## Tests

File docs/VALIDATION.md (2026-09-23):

# Rev 3.0 validation scope

The frame, skirted collet and cap have been physically printed and reported stable and usable by the designer. This is practical prototype feedback, not a fatigue-life or impact certification.

## Release checks

Run from the repository root with Python 3:

```sh
python3 scripts/verify_release.py
```

The release verifier checks the three STL meshes for open/nonmanifold edges, inconsistent winding, duplicate triangles and degenerate-index triangles. It expects nine disconnected components in the frame mesh (frame plus eight moving flaps) and one each for cap and collet. These checks do not detect every possible self-intersection or establish mechanical strength.

It also verifies each 3MF's ZIP integrity, XML/JSON readability, absence of machine-ready G-code, eight frame modifiers, two frame-colour parts and two handle components. Saved machine and material assignments are recorded in `verification/release.json`. Website validation and download packaging are maintained in the separate website repository.

`verification/mesh-qa.json` records the exported STL geometry; `verification/partition-check.json` records the earlier text partition check. The digital partition recombined to the original envelope within numerical precision, with no text outside that envelope. The text is 0.60 mm deep.

## Earlier checks and their limits

The original Rev 3.0 lettering was checked for assembled orientation and all 36 glyph islands had coloured toolpaths in the first three 0.20 mm layers during an earlier native Bambu Studio 02.08.03.66 slice. The current projects subsequently received user-saved machine/material settings. That earlier slice is not certification of the current saved profile combination.

The latest projects remain unsliced. Re-slice them for your actual machine and inspect the bed layout, first-layer contact, moving clearances, bridges and colour assignments. Coloured surface finish, mixed-material bonding and long-term durability require physical validation.

## Accessories supplement

The user selected the tightest equal-wall cap (ID 21.44, OD 23.84, wall 1.20 mm) and approved the final logo version for inclusion. The user reports the D hanger works very well. This is practical fit/use feedback, not a measured load rating or fatigue test. The logo was verified digitally to preserve the selected cap envelope. Accessory reports include native slicing, part alignment and mesh checks. Release promotion changes names and documentation only; STL hashes and all 3MF mesh payloads are preserved.

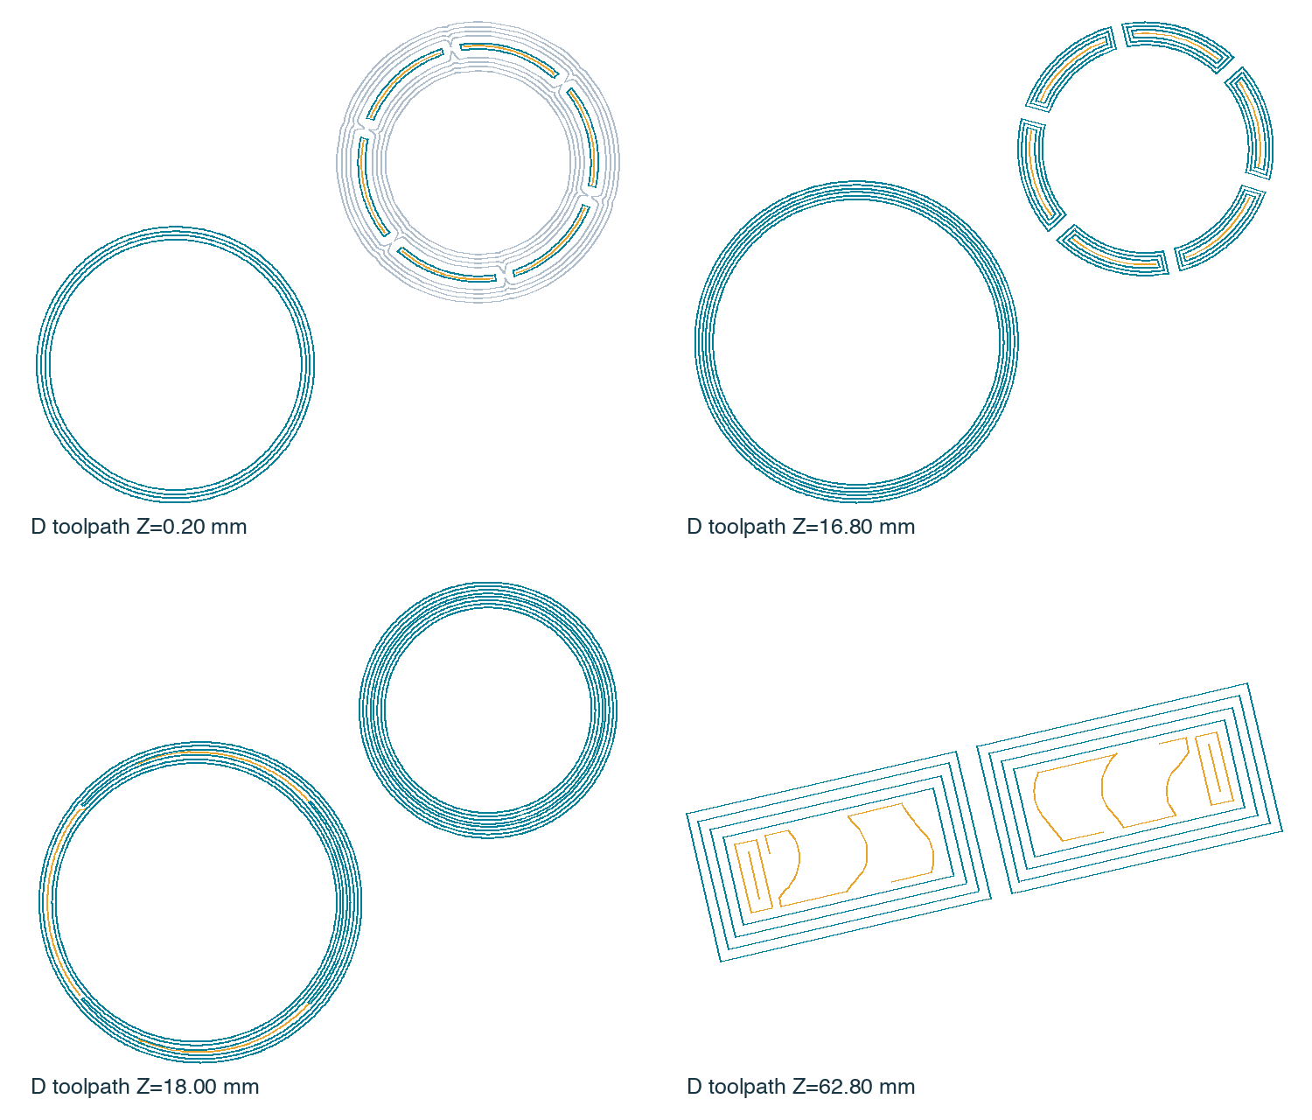
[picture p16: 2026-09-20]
Accessories/Hanger/verification/D-toolpath-sections.png

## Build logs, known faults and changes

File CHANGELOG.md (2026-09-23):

# Changelog

## Accessories supplement — 2026-09-22

- Add `Accessories/EndCap`: user-selected ID 21.44 / OD 23.84 / wall 1.20 mm cap with flush two-colour paddle-and-ball logo.
- Add `Accessories/Hanger`: user-tested removable D hanger and compression nut.
- Retire trial directories and prototype filenames from the published tree.
- Include both accessories in the Maker Bundle and editable-design download; add a standalone Accessories ZIP.
- Keep the original `v3.0` tag and core CAD/STL/3MF files unchanged; refreshed bundles identify their source commit.

## 3.0 — 2026-09-14

First public release at [Tia-Lin/PongFetch](https://github.com/Tia-Lin/PongFetch), tag `v3.0`.

- Current validated three-part mechanical kit: integrated-latch frame, locating-skirt collet and removable screw cap.
- Eight side-release latches with four net pins each, shallow blended net guides, and three internal first-layer breakaway ties per flap.
- Flat 1.2 mm fin bases and smooth fin-root and handle-mount transitions.
- Flush two-colour labels readable after assembly: PongFetch / Pick.Play. / open source / rev 3.0.
- Latest saved frame and handle-parts 3MF projects, three STL meshes, editable OpenSCAD files, assembly and printing documentation.
- CC BY-NC-SA 4.0 design license, attribution and third-party notices.
- Generated download packages are release assets, not duplicate tracked files.

Publication does not change existing mechanical geometry or saved print settings. The mechanical baseline has physical print feedback; new colour finish and long-term durability are not certified. Earlier private prototype revisions are not included in this repository's public history.

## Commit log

2026-09-14 Release PongFetch 3.0 with current print kit and CC BY-NC-SA documentation
    [Branding.scad, Collet.stl, ColletCap.stl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]
2026-09-20 Add thin end cap and removable clamp hanger prototypes
    [A_Prototype_X2D_PETG_Basic.3mf, A_body.stl, A_fit_ring.stl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]
2026-09-20 Refine decorative cap retention with same-height fit trials
    [A2_Fit_Comparison_X2D_PETG_Basic.3mf, A2_firm.stl, A2_medium.stl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]
2026-09-21 Reduce end-cap bore around tested Firm ribs and retire loose trials
    [A2_Fit_Comparison_X2D_PETG_Basic.3mf, A2_medium.stl, A3_ID21_44.stl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]
2026-09-21 Keep A3 cap walls at 1.20 mm by reducing outer diameters
    [A3_ID21_44.stl, A3_ID21_54.stl, A3_Reduced_ID_X2D_PETG_Basic.3mf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]
2026-09-22 Finalize selected end cap with flush two-colour paddle logo
    [A3_ID21_54.stl, A3_Reduced_ID_X2D_PETG_Basic.3mf, A3_firm.stl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]
2026-09-23 Publish end cap and hanger together as Accessories
    [D_Prototype_X2D_PETG_Basic.3mf, EndCap.scad, EndCap_body.stl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]
